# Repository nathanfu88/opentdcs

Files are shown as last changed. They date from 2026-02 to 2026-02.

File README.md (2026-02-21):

# opentDCS

Open Source Transcranial Direct Current Stimulation (tDCS) Device.

## Project Structure

This monorepo contains the following components:

- **[firmware/](firmware/)**: ESP32 firmware for the tDCS device.
- **[kicad/](kicad/)**: Hardware design (schematics and PCB layout).
- **[mobile/](mobile/)**: Mobile application for controlling the device via BLE.

## Circuit
### Core Circuit
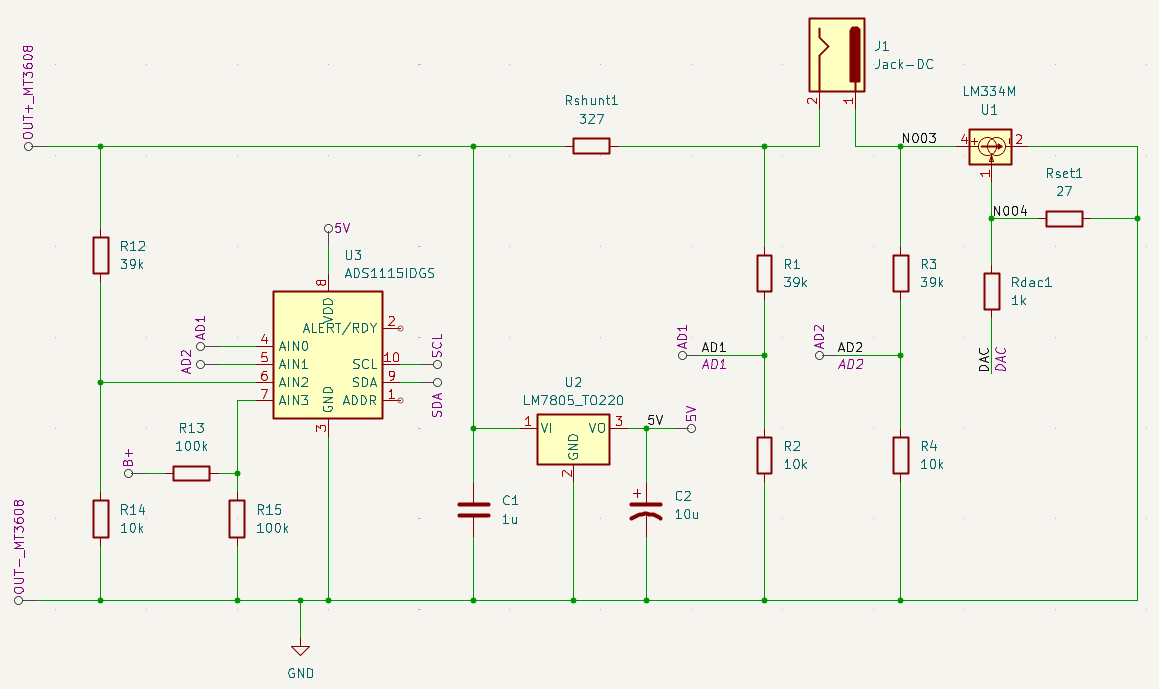
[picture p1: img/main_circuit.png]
Core circuit


### Power Management Circuit
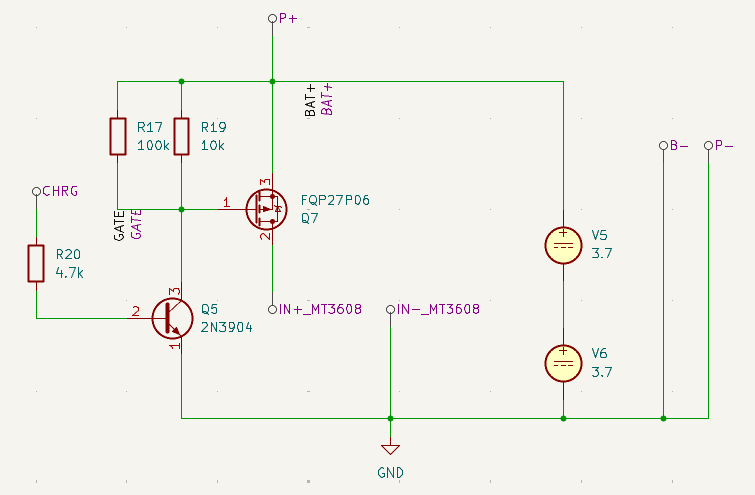
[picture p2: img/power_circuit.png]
Power circuit


## Bill of Materials (BOM)

The following hardware components are required for the opentDCS project. 

### Core Components
| Component | Part Number / Value | Quantity | Description | Purpose |
|---|---|---|---| --- |
| Microcontroller | ESP32-WROOM-32 | 1 | Main controller with BLE support | Circuit controller |
| ADC | ADS1115IDGS | 1 | 16-bit precision ADC with I2C interface | Circuit monitoring |
| Voltage Regulator | LM7805 | 1 | 5V Linear Regulator | Voltage regulation |
| Current Source | LM334M | 1 | Adjustable current source | Current controller |
| MOSFET (P-Ch) | FQP27P06 | 1 | High-side power switching | Safety switching during charging |
| BJT (NPN) | 2N3904 | 1 | General purpose transistor | Power circuit control |
| Boost Converter | MT3608 Module | 1 | DC voltage boost | Boost voltage for current targets |
| Li-ion Charger | 2S BMS Charging Module | 1 | 2-cell Series Battery Management System | Battery charging |
| Battery | 3.7V 18650 Li-ion | 2 | High-capacity rechargeable power source | Power source |

### Passives & Connectors
| Type | Value | Quantity | References |
|---|---|---|---|
| Resistor | 39kΩ | 3 | R1, R3, R12 |
| Resistor | 10kΩ | 4 | R2, R4, R14, R19 |
| Resistor | 100kΩ | 3 | R13, R15, R17 |
| Resistor | 4.7kΩ | 1 | R20 |
| Resistor | 1kΩ | 1 | Rdac1 |
| Resistor | 327Ω | 1 | Rshunt1 |
| Resistor | 27Ω | 1 | Rset1 |
| Capacitor | 1μF | 1 | C1 |
| Capacitor | 10μF (Polarized) | 1 | C2 |
| Connector | DC Barrel Jack | 1 | J1 |

## Quick Start

Please refer to the README files in each subdirectory for rough instructions:

- [Hardware Circuit Design](kicad/README.md)
- [Firmware Setup](firmware/README.md)
- [Mobile App](mobile/README.md)

## License

See the [LICENSE](LICENSE) file for details.

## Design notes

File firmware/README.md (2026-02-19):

# opentDCS Firmware

ESP32 firmware for the opentDCS device, built with ESP-IDF.

## Features

- **BLE Control**: GATT server for remote control via mobile app
- **Safety**: DAC control with failsafe defaults
- **Monitoring**: ADS1115 16-bit ADC for precise current/voltage monitoring. ADC values over BLE

## Hardware Pinout

| Function | ESP32 Pin | Description |
|---|---|---|
| I2C SDA  | GPIO 21 | ADS1115 Data |
| I2C SCL  | GPIO 22 | ADS1115 Clock |
| DAC Out  | GPIO 25 | Current Control (DAC Chan 0) |

## BLE Specification

- **Service UUID**: `000000ff-0000-1000-8000-00805f9b34fb` (16-bit: `0x00FF`)
- **Characteristic UUID**: `0000ff01-0000-1000-8000-00805f9b34fb` (16-bit: `0xFF01`)
- **Device Name**: `tDCS`

### Data Protocol

- **Write (1 byte)**: Set DAC value.
    - `0-252`: Set DAC output (Note: 0 is Max Current, 255 is Min Current)
    - `253`: Disable DAC (Safe Mode)
    - `254`: Enable DAC

- **Read (8 bytes)**: Raw ADC values from ADS1115.
    - Bytes 0-1: Channel 0
    - Bytes 2-3: Channel 1
    - Bytes 4-5: Channel 2
    - Bytes 6-7: Channel 3
    - (Big Endian)

## Quickstart

1.  **Install ESP-IDF**: Follow the [official guide](https://docs.espressif.com/projects/esp-idf/en/latest/esp32/get-started/)
2.  **Build & Flash**:
    ```bash
    idf.py set-target esp32
    idf.py build
    idf.py -p <YOUR_PORT> flash monitor
    ```

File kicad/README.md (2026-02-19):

# opentDCS Hardware

KiCad schematic file for the opentDCS hardware. PCB file is not confirmed nor validated yet.

## Files

- **opentDCS.kicad_sch**: Current control circuit schematic file. The ESP32 block is not shown in the schematic. Named pins in the schematic connect to the designated ESP32 pins.
- **power.kicad_sch**: Power circuit schematic file. 2BMS charger circuit is not shown in the schematic, nor is the DC boost unit (MT3608). Connect the named pins in the schematic to the respective circuit.

## Quickstart

1.  **Install KiCad**: Download from [kicad.org](https://www.kicad.org/)
2.  **Open Project**:
    -   Launch KiCad
    -   Open `opentDCS.kicad_pro`
    -   Open `opentDCS.kicad_sch` to view schematics

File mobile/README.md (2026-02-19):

# opentDCS Mobile Controller App

A minimal Flutter application for controlling ESP32-based opentDCS via Bluetooth.

## Features

### Core Functionality
- **BLE Connection**: Scan and connect to ESP32 devices
- **Intensity Control**: Set output current (0-2mA) with safety validation
- **Duration Control**: Set session duration (10/20/30 minutes)
- **ADC Monitoring**: ADC data reporting (4 channels)
- **Session Timer**: Auto-stop when duration completes
- **Safety Validation**: Range checks and DAC conversion validation

## Project Structure

```
mobile/
├── lib/
│   ├── main.dart                    # App entry + navigation
│   ├── models/
│   │   └── models.dart              # SessionConfig, ADCReading, ConnectionState
│   ├── services/
│   │   └── ble_service.dart         # BLE communication (~280 lines)
│   └── screens/
│       ├── connect_screen.dart      # Device scanning & connection
│       ├── control_screen.dart      # Intensity/duration controls + session
│       └── monitor_screen.dart      # ADC data display
└── pubspec.yaml                     # Dependencies
```

## Quickstart

1.  **Install Flutter**: Follow the [official guide](https://flutter.dev/docs/get-started/install)
2.  **Run the App**:
    ```bash
    cd mobile
    flutter pub get
    flutter run
    ```

## BLE Protocol

- **Service**: `000000ff-0000-1000-8000-00805f9b34fb`
- **Characteristic**: `0000ff01-0000-1000-8000-00805f9b34fb`
- **Device Name**: `opentDCS`

## Related Projects

- **[Firmware](../firmware)**: ESP32 firmware source code
- **[Hardware](../kicad)**: KiCad schematics

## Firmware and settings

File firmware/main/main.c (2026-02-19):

#include <inttypes.h>
#include <math.h>
#include "freertos/FreeRTOS.h"
#include "freertos/task.h"
#include "soc/dac_channel.h"
#include "driver/dac_oneshot.h"
#include "driver/i2c_master.h"
#include "ads1115.h"
#include "esp_check.h"


#include <stdio.h>
#include <stdlib.h>
#include <string.h>
#include "freertos/event_groups.h"
#include "esp_system.h"
#include "esp_log.h"
#include "nvs_flash.h"
#include "esp_bt.h"

#include "esp_gap_ble_api.h"
#include "esp_gatts_api.h"
#include "esp_bt_defs.h"
#include "esp_bt_main.h"
#include "esp_bt_device.h"
#include "esp_gatt_common_api.h"

#include "sdkconfig.h"

#define I2C_MASTER_SCL_IO 22
#define I2C_MASTER_SDA_IO 21
#define I2C_MASTER_NUM I2C_NUM_0

#define GATTS_TAG "tDCS"
static const char *TAG = "tDCS";

static void gatts_profile_a_event_handler(esp_gatts_cb_event_t event, esp_gatt_if_t gatts_if, esp_ble_gatts_cb_param_t *param);

#define GATTS_SERVICE_UUID_TEST_A   0x00FF
#define GATTS_CHAR_UUID_TEST_A      0xFF01
#define GATTS_DESCR_UUID_TEST_A     0x3333
#define GATTS_NUM_HANDLE_TEST_A     4

#define DEVICE_NAME "tDCS"

#define GATTS_DEMO_CHAR_VAL_LEN_MAX 0x40

static uint8_t char1_str[] = {0x11,0x22,0x33};
static esp_gatt_char_prop_t a_property = 0;

static esp_attr_value_t gatts_demo_char1_val =
{
    .attr_max_len = GATTS_DEMO_CHAR_VAL_LEN_MAX,
    .attr_len     = sizeof(char1_str),
    .attr_value   = char1_str,
};

static uint8_t adv_config_done = 0;

static esp_ble_adv_data_t adv_data = {
    .set_scan_rsp = false,
    .include_name = true,
    .include_txpower = false,
    .min_interval = 0x0006,
    .max_interval = 0x0010,
    .appearance = 0x00,
    .manufacturer_len = 0,
    .p_manufacturer_data = NULL,
    .service_data_len = 0,
    .p_service_data = NULL,
    .service_uuid_len = 0,
    .p_service_uuid = NULL,
    .flag = (ESP_BLE_ADV_FLAG_GEN_DISC | ESP_BLE_ADV_FLAG_BREDR_NOT_SPT),
};

static esp_ble_adv_params_t adv_params = {
    .adv_int_min        = 0x20,
    .adv_int_max        = 0x40,
    .adv_type           = ADV_TYPE_IND,
    .own_addr_type      = BLE_ADDR_TYPE_PUBLIC,
    //.peer_addr            =
    //.peer_addr_type       =
    .channel_map        = ADV_CHNL_ALL,
    .adv_filter_policy = ADV_FILTER_ALLOW_SCAN_ANY_CON_ANY,
};

#define PROFILE_NUM 1
#define PROFILE_A_APP_ID 0

struct gatts_profile_inst {
    esp_gatts_cb_t gatts_cb;
    uint16_t gatts_if;
    uint16_t app_id;
    uint16_t conn_id;
    uint16_t service_handle;
    esp_gatt_srvc_id_t service_id;
    uint16_t char_handle;
    esp_bt_uuid_t char_uuid;
    esp_gatt_perm_t perm;
    esp_gatt_char_prop_t property;
    uint16_t descr_handle;
    esp_bt_uuid_t descr_uuid;
};

/* One gatt-based profile one app_id and one gatts_if, this array will store the gatts_if returned by ESP_GATTS_REG_EVT */
static struct gatts_profile_inst gl_profile_tab[PROFILE_NUM] = {
    [PROFILE_A_APP_ID] = {
        .gatts_cb = gatts_profile_a_event_handler,
        .gatts_if = ESP_GATT_IF_NONE,       /* Not get the gatt_if, so initial is ESP_GATT_IF_NONE */
    },
};

static ads1115_handle_t ads1115_dev;
static i2c_master_bus_handle_t i2c_bus_handle;
static uint8_t dac_out_val = 0;
static bool dac_enabled = false;

// IMPORTANT: Circuit has INVERSE relationship between DAC voltage and output current
// DAC 0 (0V) = Maximum current (~2.48mA)
// DAC 255 (3.3V) = Minimal current (~0.007mA)
// For safety: when disabled, DAC should be set to 255 (high voltage = low current)

static void gap_event_handler(esp_gap_ble_cb_event_t event, esp_ble_gap_cb_param_t *param)
{
    switch (event) {
    case ESP_GAP_BLE_ADV_DATA_SET_COMPLETE_EVT:
        adv_config_done = 1;
        if (adv_config_done) {
            esp_ble_gap_start_advertising(&adv_params);
        }
        break;
    case ESP_GAP_BLE_ADV_START_COMPLETE_EVT:
        if (param->adv_start_cmpl.status != ESP_BT_STATUS_SUCCESS) {
            ESP_LOGE(GATTS_TAG, "Advertising start failed");
        }
        break;
    case ESP_GAP_BLE_ADV_STOP_COMPLETE_EVT:
        if (param->adv_stop_cmpl.status != ESP_BT_STATUS_SUCCESS) {
            ESP_LOGE(GATTS_TAG, "Advertising stop failed");
        }
        break;
    default:
        break;
    }
}

static void handle_dac_write(uint8_t value) {
    if (value == 254) {
        dac_enabled = true;
        ESP_LOGI(GATTS_TAG, "DAC ENABLED");
    } else if (value == 253) {
        dac_enabled = false;
        ESP_LOGI(GATTS_TAG, "DAC DISABLED");
    } else {
        dac_out_val = value;
    }
}

static esp_err_t i2c_master_init(void)
{
    i2c_master_bus_config_t i2c_mst_config = {
        .clk_source = I2C_CLK_SRC_DEFAULT,
        .i2c_port = I2C_MASTER_NUM,
        .scl_io_num = I2C_MASTER_SCL_IO,
        .sda_io_num = I2C_MASTER_SDA_IO,
        .glitch_ignore_cnt = 7,
        .flags.enable_internal_pullup = true,
    };

    return i2c_new_master_bus(&i2c_mst_config, &i2c_bus_handle);
}

static esp_err_t ads1115_setup(void)
{
    ads1115_config_t config = {
        .addr = ADS1115_I2C_ADDR_DEFAULT,
        .gain = ADS1115_PGA_4_096V,
        .data_rate = ADS1115_DR_64SPS
    };
    return ads1115_init(&ads1115_dev, &config, i2c_bus_handle);
}

static void gatts_read_adc(esp_gatt_if_t gatts_if, esp_ble_gatts_cb_param_t *param) {
    int16_t chan0_raw = 0;
    int16_t chan1_raw = 0;
    int16_t chan2_raw = 0;
    int16_t chan3_raw = 0;
    esp_err_t ret;

    ret = ads1115_read_single(&ads1115_dev, ADS1115_MUX_SINGLE_0, &chan0_raw);
    if (ret != ESP_OK) {
        ESP_LOGE(GATTS_TAG, "Failed to read ADS1115 A0: %s", esp_err_to_name(ret));
        chan0_raw = 0;
    }

    ret = ads1115_read_single(&ads1115_dev, ADS1115_MUX_SINGLE_1, &chan1_raw);
    if (ret != ESP_OK) {
        ESP_LOGE(GATTS_TAG, "Failed to read ADS1115 A1: %s", esp_err_to_name(ret));
        chan1_raw = 0;
    }

    ret = ads1115_read_single(&ads1115_dev, ADS1115_MUX_SINGLE_2, &chan2_raw);
    if (ret != ESP_OK) {
        ESP_LOGE(GATTS_TAG, "Failed to read ADS1115 A2: %s", esp_err_to_name(ret));
        chan2_raw = 0;
    }

    ret = ads1115_read_single(&ads1115_dev, ADS1115_MUX_SINGLE_3, &chan3_raw);
    if (ret != ESP_OK) {
        ESP_LOGE(GATTS_TAG, "Failed to read ADS1115 A3: %s", esp_err_to_name(ret));
        chan3_raw = 0;
    }

    esp_gatt_rsp_t rsp;
    memset(&rsp, 0, sizeof(esp_gatt_rsp_t));
    rsp.attr_value.handle = param->read.handle;
    rsp.attr_value.len = 8;
    rsp.attr_value.value[0] = (chan0_raw >> 8) & 0xFF;
    rsp.attr_value.value[1] = chan0_raw & 0xFF;
    rsp.attr_value.value[2] = (chan1_raw >> 8) & 0xFF;
    rsp.attr_value.value[3] = chan1_raw & 0xFF;
    rsp.attr_value.value[4] = (chan2_raw >> 8) & 0xFF;
    rsp.attr_value.value[5] = chan2_raw & 0xFF;
    rsp.attr_value.value[6] = (chan3_raw >> 8) & 0xFF;
    rsp.attr_value.value[7] = chan3_raw & 0xFF;
    
    esp_ble_gatts_send_response(gatts_if, param->read.conn_id, param->read.trans_id,
                                ESP_GATT_OK, &rsp);
}

static void gatts_profile_a_event_handler(esp_gatts_cb_event_t event, esp_gatt_if_t gatts_if, esp_ble_gatts_cb_param_t *param) {
    switch (event) {
    case ESP_GATTS_REG_EVT:
        gl_profile_tab[PROFILE_A_APP_ID].service_id.is_primary = true;
        gl_profile_tab[PROFILE_A_APP_ID].service_id.id.inst_id = 0x00;
        gl_profile_tab[PROFILE_A_APP_ID].service_id.id.uuid.len = ESP_UUID_LEN_16;
        gl_profile_tab[PROFILE_A_APP_ID].service_id.id.uuid.uuid.uuid16 = GATTS_SERVICE_UUID_TEST_A;

        esp_ble_gap_set_device_name(DEVICE_NAME);
        esp_ble_gap_config_adv_data(&adv_data);
        esp_ble_gatts_create_service(gatts_if, &gl_profile_tab[PROFILE_A_APP_ID].service_id, GATTS_NUM_HANDLE_TEST_A);
        break;
    case ESP_GATTS_READ_EVT:
        gatts_read_adc(gatts_if, param);
        break;
    case ESP_GATTS_WRITE_EVT:
        if (param->write.len == 1) {
            handle_dac_write(param->write.value[0]);
        }
        if (param->write.need_rsp) {
            esp_ble_gatts_send_response(gatts_if, param->write.conn_id, param->write.trans_id, ESP_GATT_OK, NULL);
        }
        break;
    case ESP_GATTS_CREATE_EVT:
        gl_profile_tab[PROFILE_A_APP_ID].service_handle = param->create.service_handle;
        gl_profile_tab[PROFILE_A_APP_ID].char_uuid.len = ESP_UUID_LEN_16;
        gl_profile_tab[PROFILE_A_APP_ID].char_uuid.uuid.uuid16 = GATTS_CHAR_UUID_TEST_A;
        esp_ble_gatts_start_service(gl_profile_tab[PROFILE_A_APP_ID].service_handle);
        a_property = ESP_GATT_CHAR_PROP_BIT_READ | ESP_GATT_CHAR_PROP_BIT_WRITE;
        esp_ble_gatts_add_char(gl_profile_tab[PROFILE_A_APP_ID].service_handle,
                              &gl_profile_tab[PROFILE_A_APP_ID].char_uuid,
                              ESP_GATT_PERM_READ | ESP_GATT_PERM_WRITE,
                              a_property,
                              &gatts_demo_char1_val, NULL);
        break;
    case ESP_GATTS_ADD_CHAR_EVT:
        gl_profile_tab[PROFILE_A_APP_ID].char_handle = param->add_char.attr_handle;
        break;
    case ESP_GATTS_CONNECT_EVT:
        gl_profile_tab[PROFILE_A_APP_ID].conn_id = param->connect.conn_id;
        break;
    case ESP_GATTS_DISCONNECT_EVT:
        esp_ble_gap_start_advertising(&adv_params);
        break;
    default:
        break;
    }
}

static void gatts_event_handler(esp_gatts_cb_event_t event, esp_gatt_if_t gatts_if, esp_ble_gatts_cb_param_t *param)
{
    if (event == ESP_GATTS_REG_EVT) {
        if (param->reg.status == ESP_GATT_OK) {
            gl_profile_tab[param->reg.app_id].gatts_if = gatts_if;
        } else {
            return;
        }
    }

    for (int idx = 0; idx < PROFILE_NUM; idx++) {
        if (gatts_if == ESP_GATT_IF_NONE || gatts_if == gl_profile_tab[idx].gatts_if) {
            if (gl_profile_tab[idx].gatts_cb) {
                gl_profile_tab[idx].gatts_cb(event, gatts_if, param);
            }
        }
    }
}

#define DAC_AMPLITUDE 255
_Static_assert(DAC_AMPLITUDE < 256, "DAC is 8-bit");
static void dac_output_task(void *args)
{
    dac_oneshot_handle_t handle = (dac_oneshot_handle_t)args;
    while (1) {
        if (dac_enabled) {
            ESP_ERROR_CHECK(dac_oneshot_output_voltage(handle, dac_out_val));
        } else {
            ESP_ERROR_CHECK(dac_oneshot_output_voltage(handle, 255));
        }
        vTaskDelay(pdMS_TO_TICKS(500));
    }
}

void app_main(void)
{
    dac_oneshot_handle_t chan0_handle;
    dac_oneshot_config_t chan0_cfg = {.chan_id = DAC_CHAN_0};
    ESP_ERROR_CHECK(dac_oneshot_new_channel(&chan0_cfg, &chan0_handle));
    xTaskCreate(dac_output_task, "dac_output_task", 4096, chan0_handle, 5, NULL);

    ESP_ERROR_CHECK(i2c_master_init());
    ESP_ERROR_CHECK(ads1115_setup());

    esp_err_t ret = nvs_flash_init();
    if (ret == ESP_ERR_NVS_NO_FREE_PAGES || ret == ESP_ERR_NVS_NEW_VERSION_FOUND) {
        ESP_ERROR_CHECK(nvs_flash_erase());
        ret = nvs_flash_init();
    }
    ESP_ERROR_CHECK(ret);

    ESP_ERROR_CHECK(esp_bt_controller_mem_release(ESP_BT_MODE_CLASSIC_BT));

    esp_bt_controller_config_t bt_cfg = BT_CONTROLLER_INIT_CONFIG_DEFAULT();
    ret = esp_bt_controller_init(&bt_cfg);
    if (ret) {
        ESP_LOGE(GATTS_TAG, "%s initialize controller failed: %s", __func__, esp_err_to_name(ret));
        return;
    }

    ret = esp_bt_controller_enable(ESP_BT_MODE_BLE);
    if (ret) {
        ESP_LOGE(GATTS_TAG, "%s enable controller failed: %s", __func__, esp_err_to_name(ret));
        return;
    }

    ret = esp_bluedroid_init();
    if (ret) {
        ESP_LOGE(GATTS_TAG, "%s init bluetooth failed: %s", __func__, esp_err_to_name(ret));
        return;
    }
    ret = esp_bluedroid_enable();
    if (ret) {
        ESP_LOGE(GATTS_TAG, "%s enable bluetooth failed: %s", __func__, esp_err_to_name(ret));
        return;
    }

    ESP_ERROR_CHECK(esp_ble_gatts_register_callback(gatts_event_handler));
    ESP_ERROR_CHECK(esp_ble_gap_register_callback(gap_event_handler));
    ESP_ERROR_CHECK(esp_ble_gatts_app_register(PROFILE_A_APP_ID));
    esp_ble_gatt_set_local_mtu(500);
}

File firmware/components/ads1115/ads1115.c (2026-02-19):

#include "ads1115.h"
#include "esp_log.h"
#include "freertos/FreeRTOS.h"
#include "freertos/task.h"

static const char *TAG = "ADS1115";

#define ADS1115_TIMEOUT_MS 1000

static esp_err_t ads1115_write_reg(ads1115_handle_t *dev, uint8_t reg, uint16_t value)
{
    uint8_t data[3];
    data[0] = reg;
    data[1] = (value >> 8) & 0xFF;  // MSB
    data[2] = value & 0xFF;         // LSB
    
    return i2c_master_transmit(dev->i2c_dev_handle, data, sizeof(data), ADS1115_TIMEOUT_MS);
}

static esp_err_t ads1115_read_reg(ads1115_handle_t *dev, uint8_t reg, uint16_t *value)
{
    esp_err_t ret;
    uint8_t data[2];
    
    ret = i2c_master_transmit_receive(dev->i2c_dev_handle, &reg, 1, data, 2, ADS1115_TIMEOUT_MS);
    if (ret != ESP_OK) {
        return ret;
    }
    
    *value = ((uint16_t)data[0] << 8) | data[1];
    return ESP_OK;
}

esp_err_t ads1115_init(ads1115_handle_t *dev, const ads1115_config_t *config, i2c_master_bus_handle_t bus_handle)
{
    if (!dev || !config || !bus_handle) {
        return ESP_ERR_INVALID_ARG;
    }
    
    dev->config = *config;
    
    // Create I2C device handle
    i2c_device_config_t dev_cfg = {
        .dev_addr_length = I2C_ADDR_BIT_LEN_7,
        .device_address = config->addr,
        .scl_speed_hz = 100000,  // 100kHz
    };
    
    esp_err_t ret = i2c_master_bus_add_device(bus_handle, &dev_cfg, &dev->i2c_dev_handle);
    if (ret != ESP_OK) {
        ESP_LOGE(TAG, "Failed to add I2C device: %s", esp_err_to_name(ret));
        return ret;
    }
    
    dev->initialized = true;
    
    ESP_LOGI(TAG, "ADS1115 initialized with address 0x%02x", config->addr);
    
    return ESP_OK;
}

esp_err_t ads1115_read_single(ads1115_handle_t *dev, uint16_t mux, int16_t *raw_value)
{
    if (!dev || !dev->initialized || !raw_value) {
        return ESP_ERR_INVALID_ARG;
    }
    
    esp_err_t ret;
    uint16_t config_reg;
    uint16_t conversion_reg;
    
    // Build configuration register value
    config_reg = ADS1115_OS_SINGLE |    // Start single conversion
                 mux |                   // Input multiplexer
                 dev->config.gain |      // Gain setting
                 ADS1115_CMODE_TRAD |    // Traditional comparator
                 ADS1115_CPOL_ACTVLOW |  // Comparator polarity
                 ADS1115_CLAT_NONLAT |   // Non-latching comparator
                 ADS1115_CQUE_NONE |     // Disable comparator
                 dev->config.data_rate;  // Data rate
    
    // Write configuration to start conversion
    ESP_LOGD(TAG, "Starting conversion with config: 0x%04X (mux=0x%04X, gain=0x%04X, rate=0x%04X)", 
             config_reg, mux, dev->config.gain, dev->config.data_rate);
    
    ret = ads1115_write_reg(dev, ADS1115_REG_CONFIG, config_reg);
    if (ret != ESP_OK) {
        ESP_LOGE(TAG, "Failed to write config register: %s", esp_err_to_name(ret));
        return ret;
    }
    
    // Verify the write was successful by reading back
    uint16_t readback_config;
    ret = ads1115_read_reg(dev, ADS1115_REG_CONFIG, &readback_config);
    if (ret == ESP_OK) {
        ESP_LOGD(TAG, "Config readback: 0x%04X (expected: 0x%04X)", readback_config, config_reg);
        if ((readback_config & ~ADS1115_OS_NOTBUSY) != (config_reg & ~ADS1115_OS_NOTBUSY)) {
            ESP_LOGW(TAG, "Config readback mismatch - I2C communication issue?");
        }
    }
    
    // Wait for conversion to complete using fixed delay
    // Calculate delay based on data rate with sufficient margin for reliability
    uint32_t delay_ms;
    switch (dev->config.data_rate) {
        case ADS1115_DR_8SPS:   delay_ms = 130; break;  // ~125ms theoretical + margin
        case ADS1115_DR_16SPS:  delay_ms = 70;  break;  // ~62.5ms theoretical + margin
        case ADS1115_DR_32SPS:  delay_ms = 35;  break;  // ~31.25ms theoretical + margin
        case ADS1115_DR_64SPS:  delay_ms = 20;  break;  // ~15.6ms theoretical + margin
        case ADS1115_DR_128SPS: delay_ms = 10;  break;  // ~7.8ms theoretical + margin
        case ADS1115_DR_250SPS: delay_ms = 5;   break;  // ~4ms theoretical + margin
        case ADS1115_DR_475SPS: delay_ms = 3;   break;  // ~2.1ms theoretical + margin
        case ADS1115_DR_860SPS: delay_ms = 2;   break;  // ~1.16ms theoretical + margin
        default:                delay_ms = 10;  break;
    }
    
    ESP_LOGD(TAG, "Waiting %u ms for conversion to complete", (unsigned)delay_ms);
    vTaskDelay(pdMS_TO_TICKS(delay_ms));
    
    // Read conversion result
    ret = ads1115_read_reg(dev, ADS1115_REG_CONVERSION, &conversion_reg);
    if (ret != ESP_OK) {
        ESP_LOGE(TAG, "Failed to read conversion register: %s", esp_err_to_name(ret));
        return ret;
    }
    
    *raw_value = (int16_t)conversion_reg;
    ESP_LOGD(TAG, "Conversion successful: raw=0x%04X (%d)", conversion_reg, *raw_value);
    return ESP_OK;
}

esp_err_t ads1115_read_voltage(ads1115_handle_t *dev, uint16_t mux, float *voltage)
{
    if (!voltage) {
        return ESP_ERR_INVALID_ARG;
    }
    
    int16_t raw_value;
    esp_err_t ret = ads1115_read_single(dev, mux, &raw_value);
    if (ret != ESP_OK) {
        return ret;
    }
    
    *voltage = ads1115_raw_to_voltage(raw_value, dev->config.gain);
    return ESP_OK;
}

float ads1115_raw_to_voltage(int16_t raw_value, uint16_t gain)
{
    float lsb_size;
    
    // Determine LSB size based on gain setting
    switch (gain) {
        case ADS1115_PGA_6_144V: lsb_size = 0.1875f; break;  // mV per LSB
        case ADS1115_PGA_4_096V: lsb_size = 0.125f;  break;
        case ADS1115_PGA_2_048V: lsb_size = 0.0625f; break;
        case ADS1115_PGA_1_024V: lsb_size = 0.03125f; break;
        case ADS1115_PGA_0_512V: lsb_size = 0.015625f; break;
        case ADS1115_PGA_0_256V: lsb_size = 0.0078125f; break;
        default:                 lsb_size = 0.125f;   break;  // Default to 4.096V range
    }
    
    return (float)raw_value * lsb_size;  // Returns voltage in mV
}

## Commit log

2026-02-19 Add project files
    [opentDCS.kicad_pcb, opentDCS.kicad_sch, power.kicad_sch]
2026-02-21 Switch to default light mode
2026-02-21 Refactor UI for Material 3 and better usability
2026-02-21 Fix reported calculations from ADC
2026-02-21 Add circuit images
2026-02-21 Add circuit images to README
